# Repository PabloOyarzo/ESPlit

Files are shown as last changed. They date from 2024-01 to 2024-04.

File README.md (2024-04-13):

---
{}
---
# ESPlit

The ESPlit is an Ergonomic Split Keyboard based on the ESP32. Uses CHOC style switches, LiPo Battery and I2C connection through QWIC and TRRS connectors. 

[v0.2-alpha - KICAD Web view from KiCanvas](https://kicanvas.org/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)

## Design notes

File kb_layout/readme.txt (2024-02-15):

steps
1- design layout at http://www.keyboard-layout-editor.com/
2- download as json
3- run on the pcb editor the Keyboard Placer
	*see kbplacer_settings.jpg*
4- use "Shift + S" to switch Switches footprint
5- run the Keyboard Placer but without a json filed loaded

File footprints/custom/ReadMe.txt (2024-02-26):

Customs
x	TRRS
	Source: Keebio
	Changes:
		-expanded the silkscreen so doesn't collide with holes

x	SK6812-MINI-E
	NEO3535 	Eagle file  -> KiCAD 
	Source: https://github.com/adafruit/Adafruit-MacroPad-RP2040-PCB
	Changes:
		-added edge cut at rule area F.Cu
		-changed led icon to F.Fab
		-changed name to SK6812-E

x	D_0805
	Same name
	Source: https://github.com/keebio/Keebio-Parts.pretty
	Changes:
		-deleted overall rectangles around F.Silkscreen
		-and also deleted little pins from center icon
		-changed layers on names and ref

x	SW_Hotswap_Kailh_Choc_V1V2_Plated_1.00u
	Same name
	Source: Package Content Manager (PCM)
		Keyswitch Kicad Library
		https://github.com/perigoso/keyswitch-kicad-library
	Changes:
		-rotated on 180 degrees for convinience used on PCM_Keyboard_footprints_placer
		-also added 3d files wrl and stp.
		-deleted bottom mask

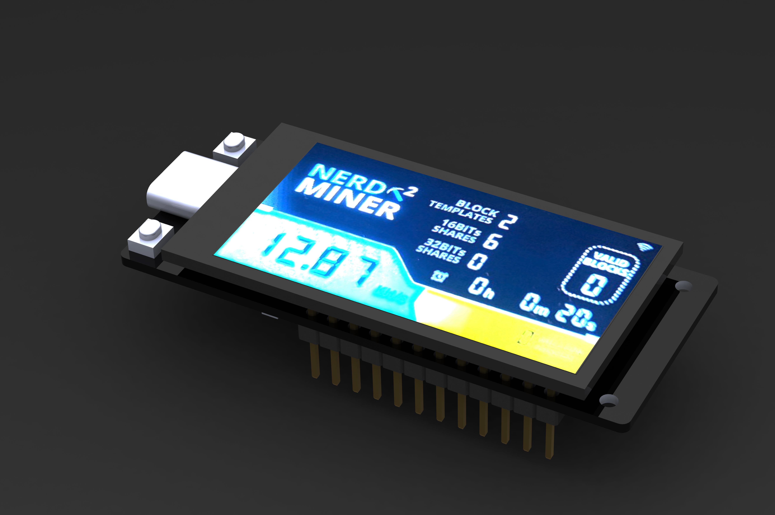
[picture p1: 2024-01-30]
footprints/T-Display-S3/board.jpg

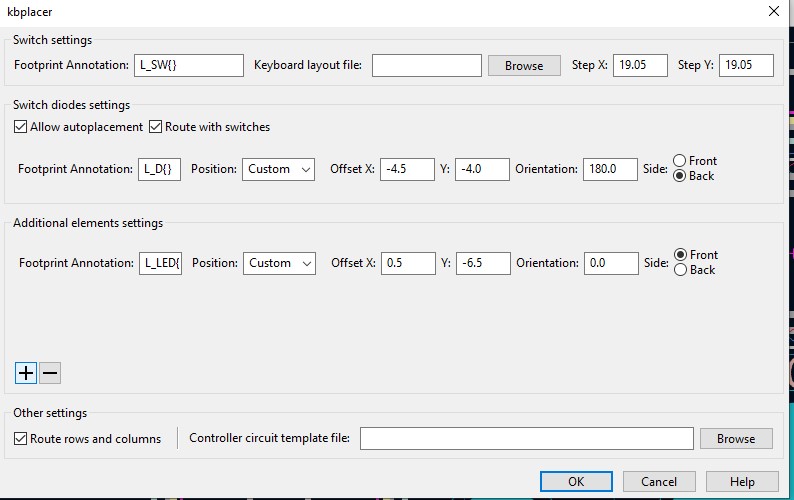
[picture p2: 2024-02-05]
kb_layout/kbplacer_settings.jpg

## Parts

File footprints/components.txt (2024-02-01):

MCU
x	T-Display-S3			https://github.com/ccadic/T-Display-S3-Kicad

MX Keys
x	MX key with Socket		https://github.com/daprice/keyswitches.pretty/tree/master
x	PRT12639 - TRRS			https://www.arrow.com/en/products/prt-12639/sparkfun-electronics

Else
x	TCA8418RTWR - IO Expander	https://www.arrow.com/en/products/tca8418rtwr/texas-instruments
x	SK6812-MINI-E RGB North facing	https://github.com/keebio/Keebio-Parts.pretty
x	0805 - Diode			https://github.com/keebio/Keebio-Parts.pretty
x	0805 - Caps			KiCAD 7
x	PCM13SMTR - Slide Switch	https://www.arrow.com/en/products/pcm13smtr/ck

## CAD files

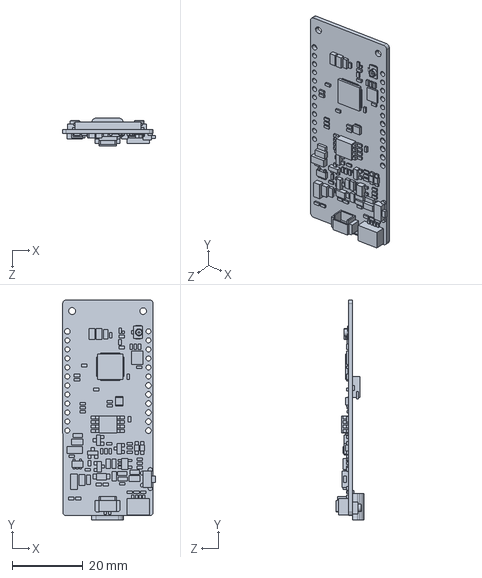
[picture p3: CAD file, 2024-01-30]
footprints/T-Display-S3/MainBoard_3D.SLDPRT
26.1 x 62.0 x 7.86 mm

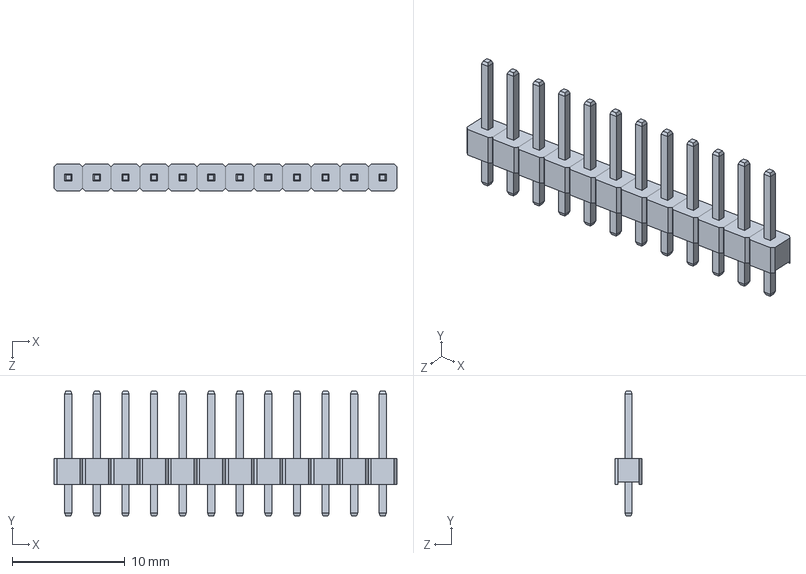
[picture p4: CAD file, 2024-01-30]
footprints/T-Display-S3/T-Display-Headers.SLDASM
30.5 x 11.1 x 2.40 mm
1_Male_Pin_2.54_mm x 12

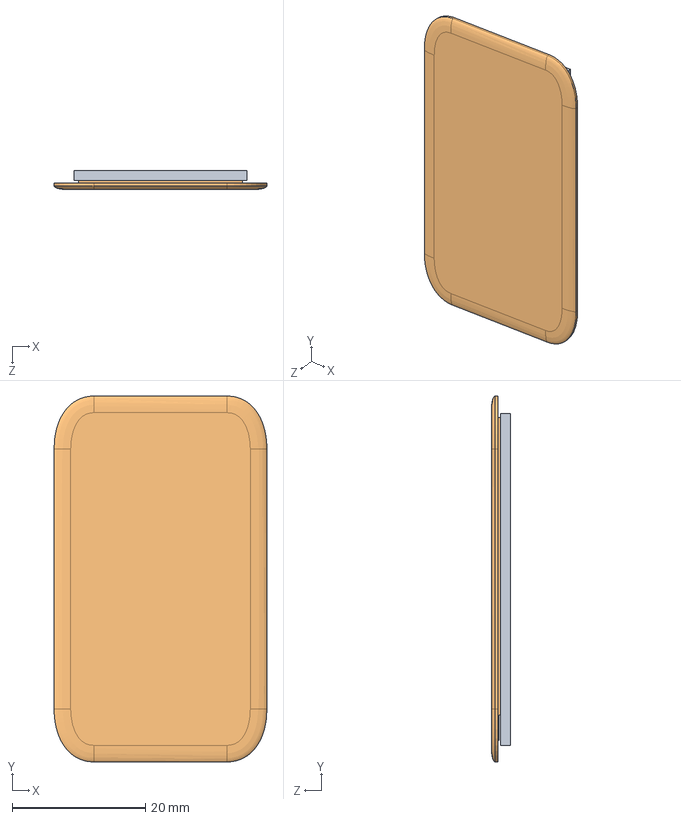
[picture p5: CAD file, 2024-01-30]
footprints/T-Display-S3/LCD_3D.SLDASM
32.0 x 55.0 x 2.93 mm

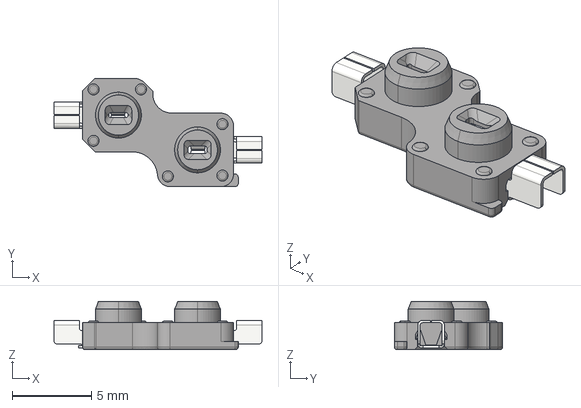
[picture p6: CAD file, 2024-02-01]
footprints/custom/SW_Hotswap_Kailh_Choc_V1.stp
13.2 x 6.85 x 3.05 mm

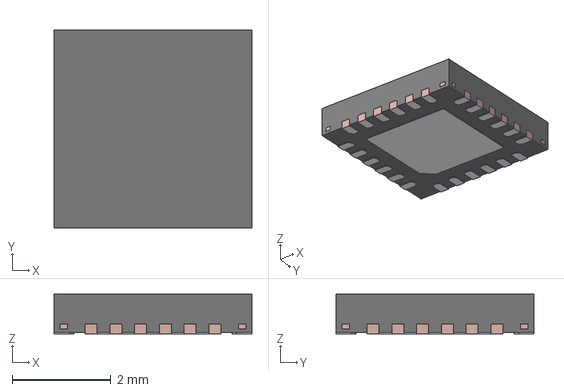
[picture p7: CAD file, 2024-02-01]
footprints/IO Expander - TCA8418RTWR/TCA8418RTWR.stp
4.00 x 4.00 x 0.8 mm
FRAME

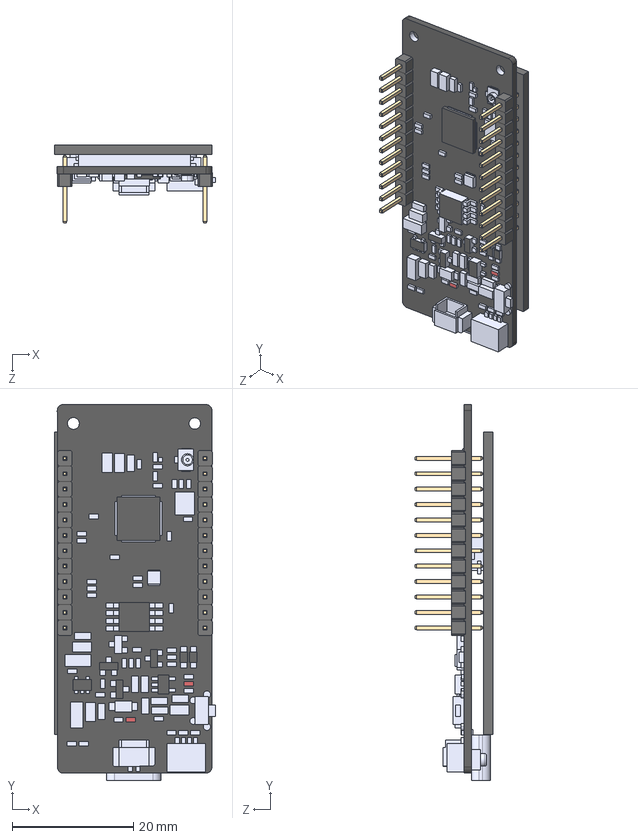
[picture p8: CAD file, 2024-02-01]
footprints/T-Display-S3/T-Display-S3.STEP
26.5 x 62.0 x 12.9 mm
MainBoard_3D
Ecran
1_Male_Pin_2.54_mm x 24

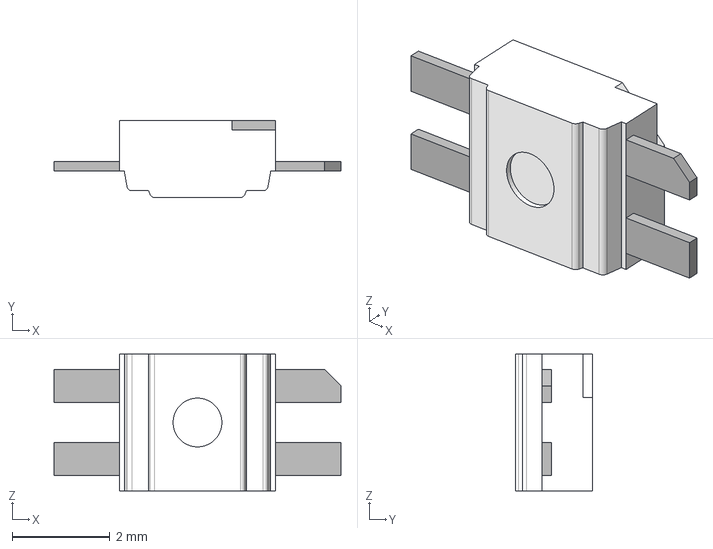
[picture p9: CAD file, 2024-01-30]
footprints/custom/SK6812-MINI-E.step
5.88 x 1.58 x 2.80 mm

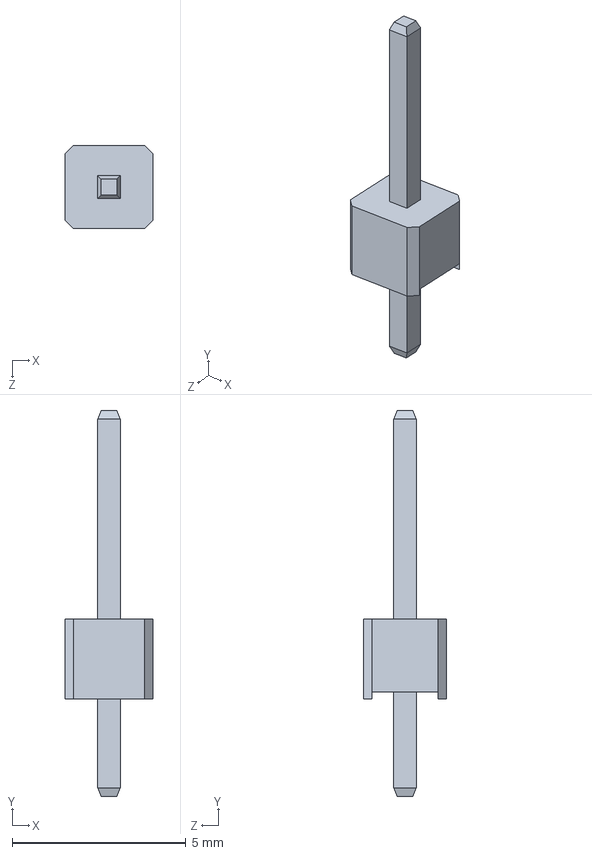
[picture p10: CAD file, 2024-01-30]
footprints/T-Display-S3/1_Male_Pin_2.54_mm.SLDPRT
2.54 x 11.1 x 2.40 mm

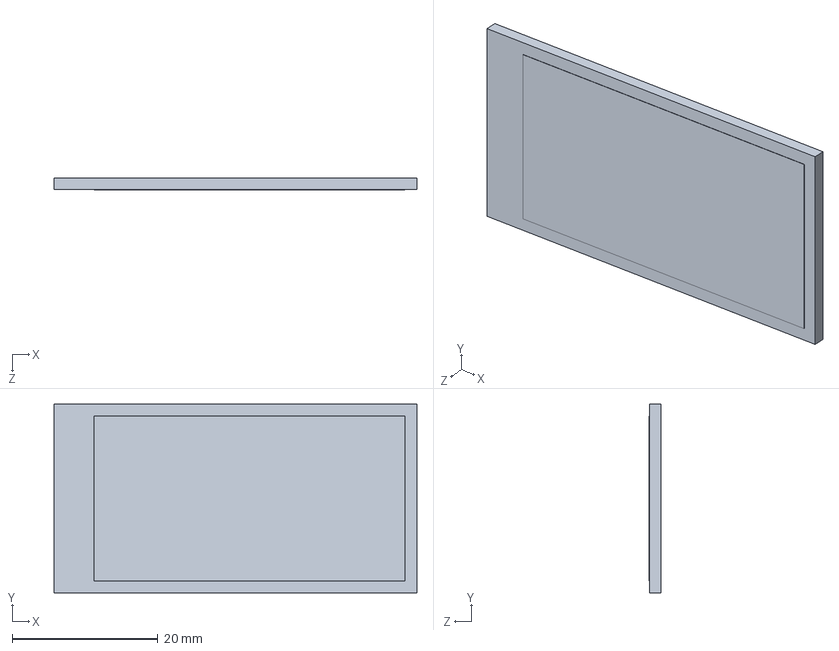
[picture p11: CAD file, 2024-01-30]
footprints/T-Display-S3/Ecran.SLDPRT
49.9 x 25.9 x 1.58 mm

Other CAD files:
footprints/T-Display-S3/T-Display-S3.SLDASM

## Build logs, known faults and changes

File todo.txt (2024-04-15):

Improvements TODO from the prototype manufactured from v0.2-alpha.

REQUIRED:
[x]	Fix Footprint:custom/SW_Hotswap_Kailh_Choc_V1V2_Plated_1.00u.kicad_mod
		> Add soldermask
[]	Change Design Rules
		> From PCBWay to => JLCPCB
[]	Add mount hole 6 to base plate
[]	Delete labels to mount holes
[]	Add pin header battery for outer port
[]	Add +/- label to Battery ports (front and back)
[]	Add label with each pin function for IO ports on top
[]	Jumper Pin 43/44
		> Add Labels
		> Make footprint bigger	
		> Further from pins 
		> Clean cut path
[]	Make hole for name on Top Plate
[]	Add Label on/off for switch
[]	Bigger font label for LED TPs
[]	Add ESD Protection to I2Cs

BETTER TO HAVE:
[]	Even rounder edge cuts
[]	Add PabloOyarzo/poka-yoke_rxtx
[]	Turn upside down pin labels for T-Display-S3

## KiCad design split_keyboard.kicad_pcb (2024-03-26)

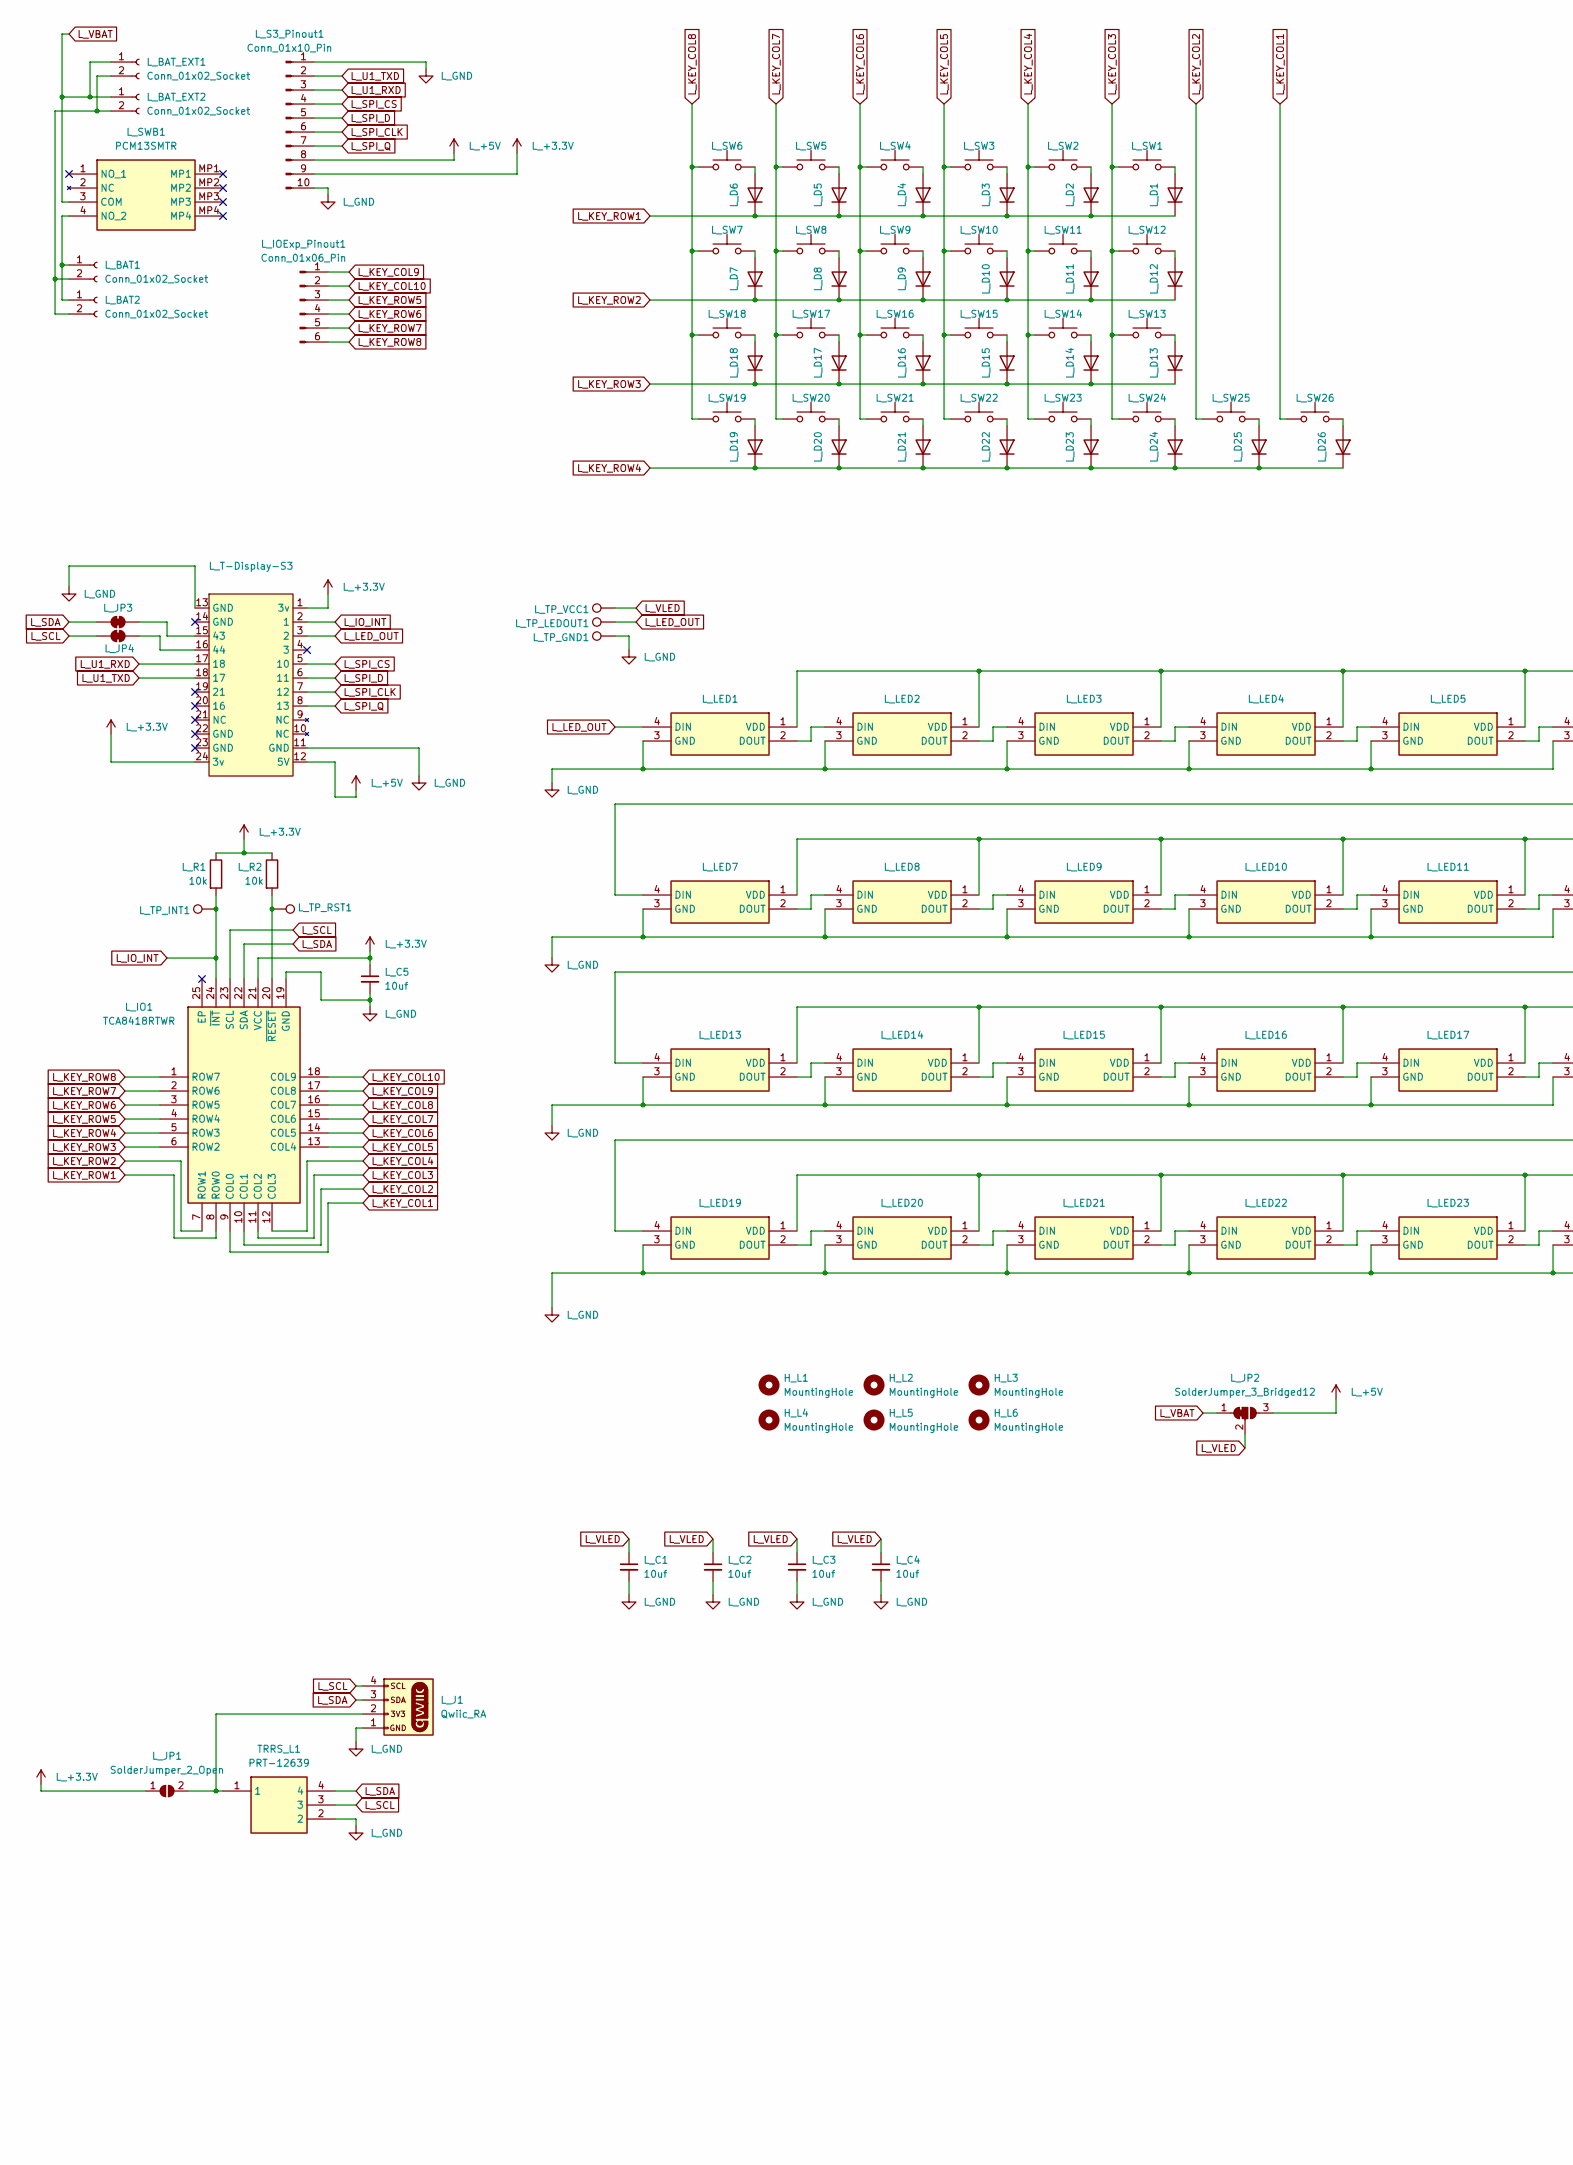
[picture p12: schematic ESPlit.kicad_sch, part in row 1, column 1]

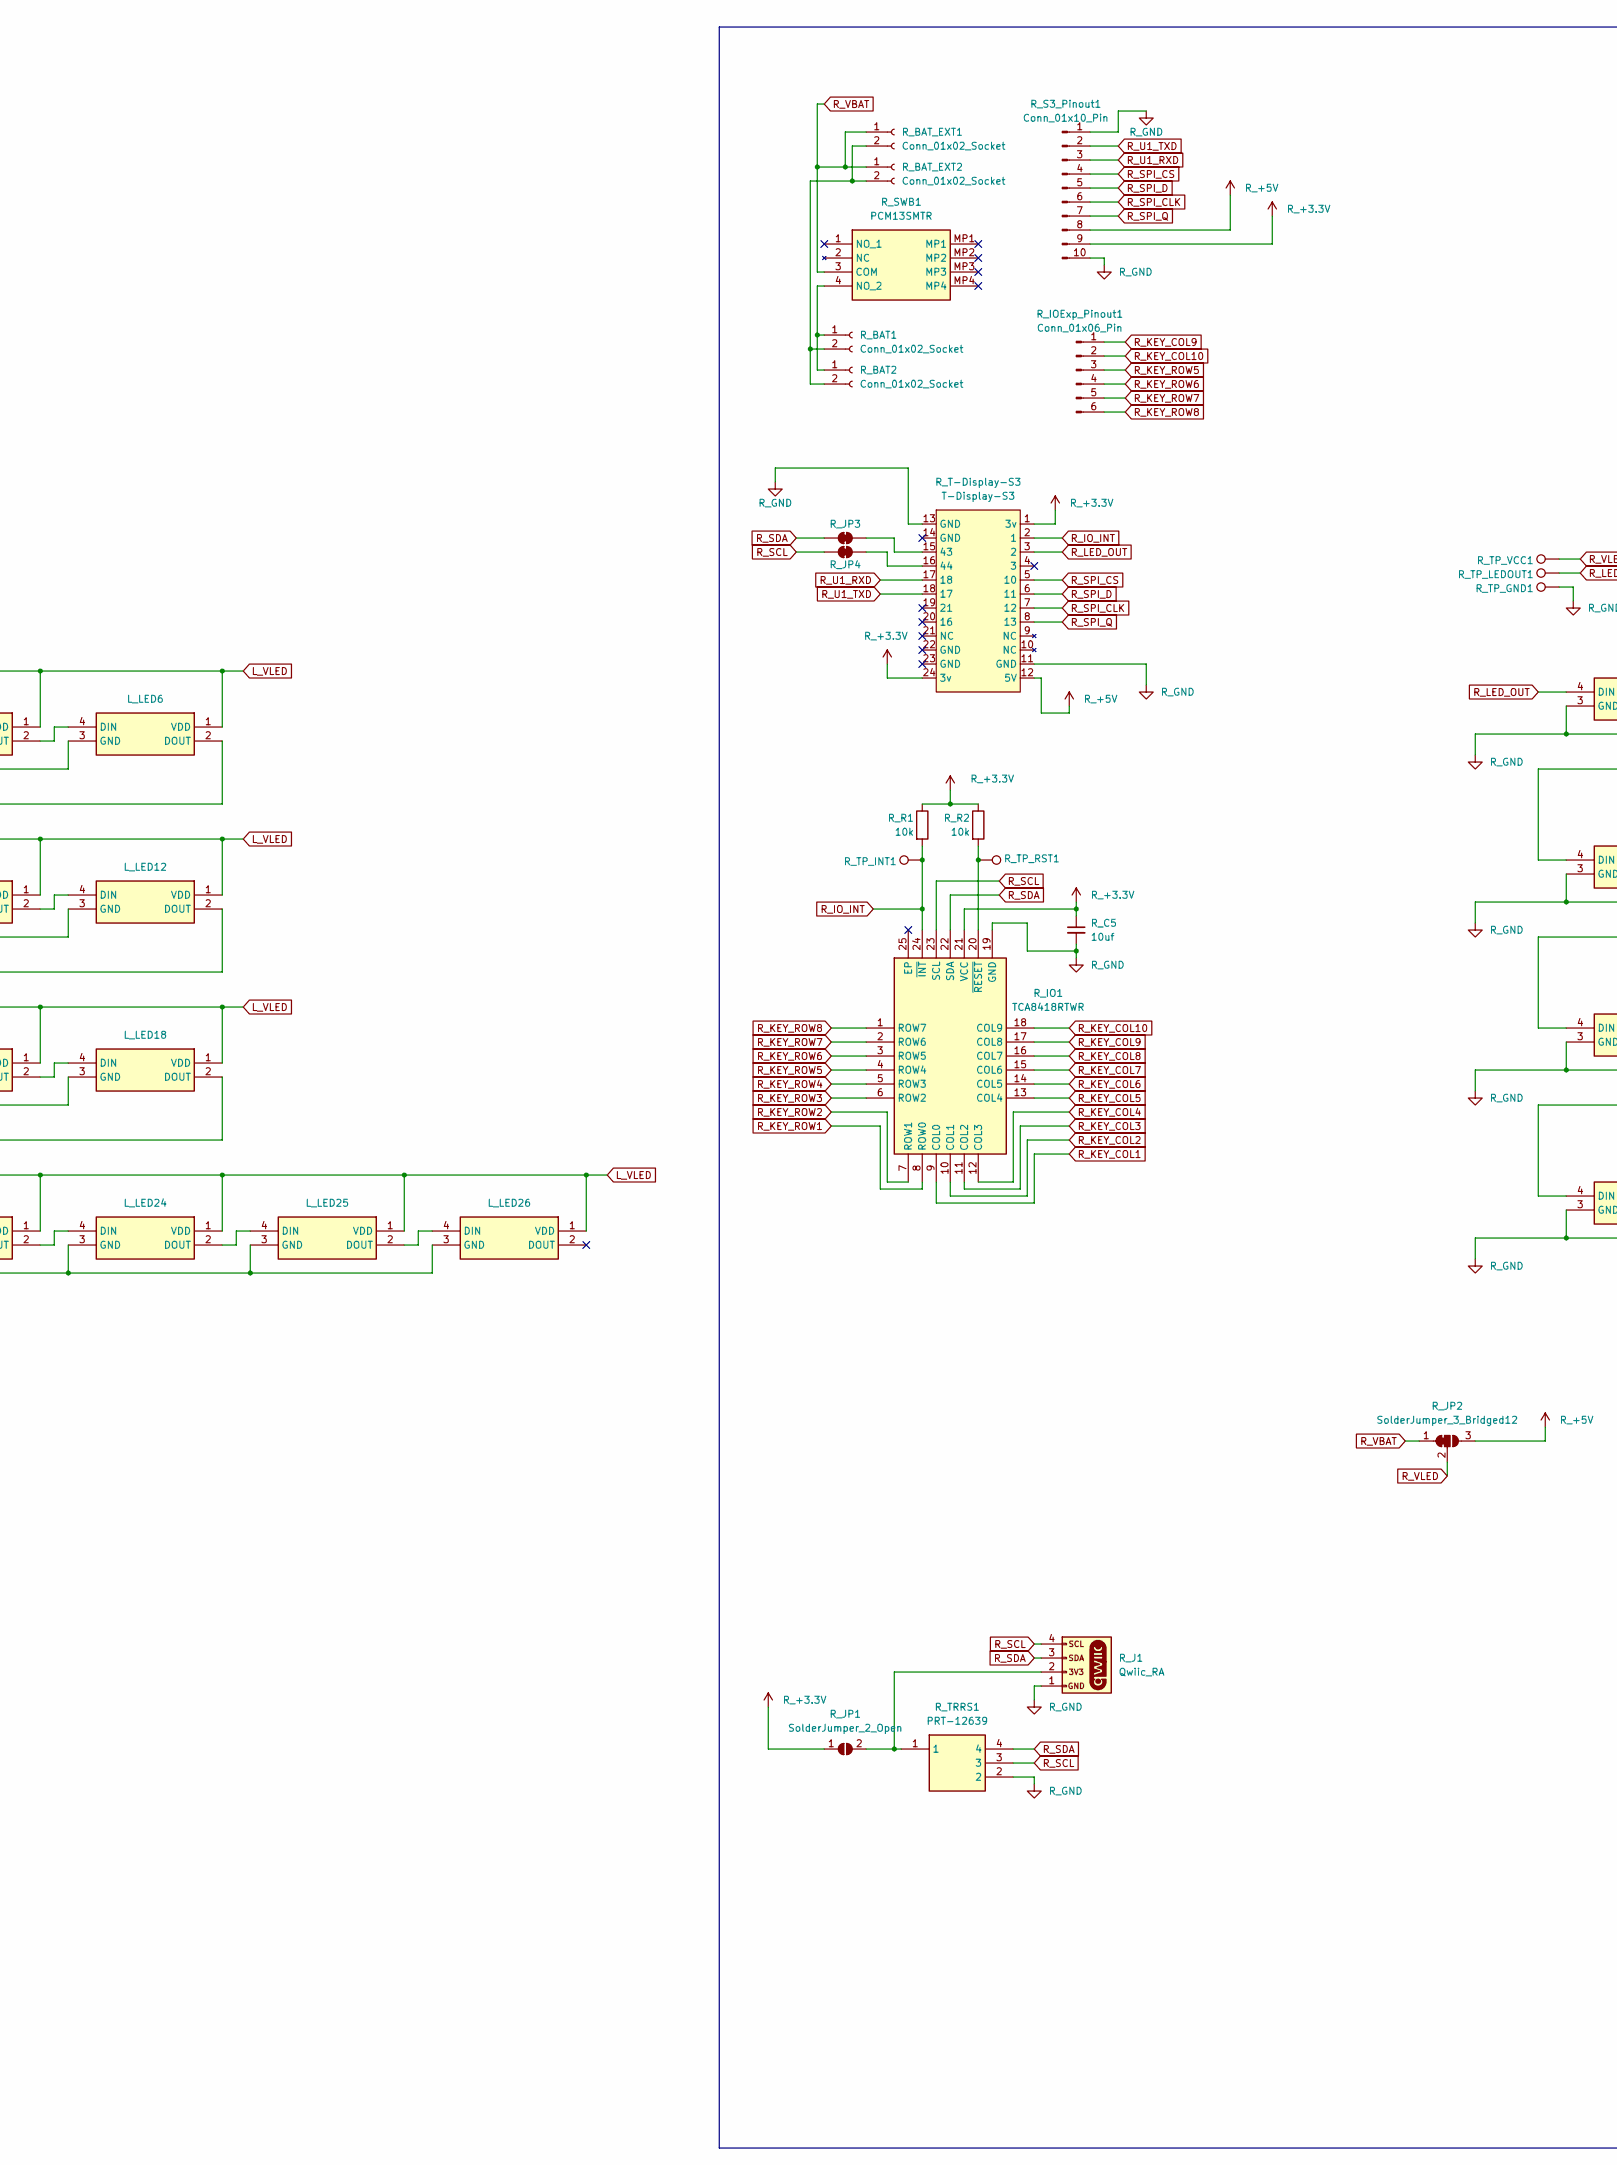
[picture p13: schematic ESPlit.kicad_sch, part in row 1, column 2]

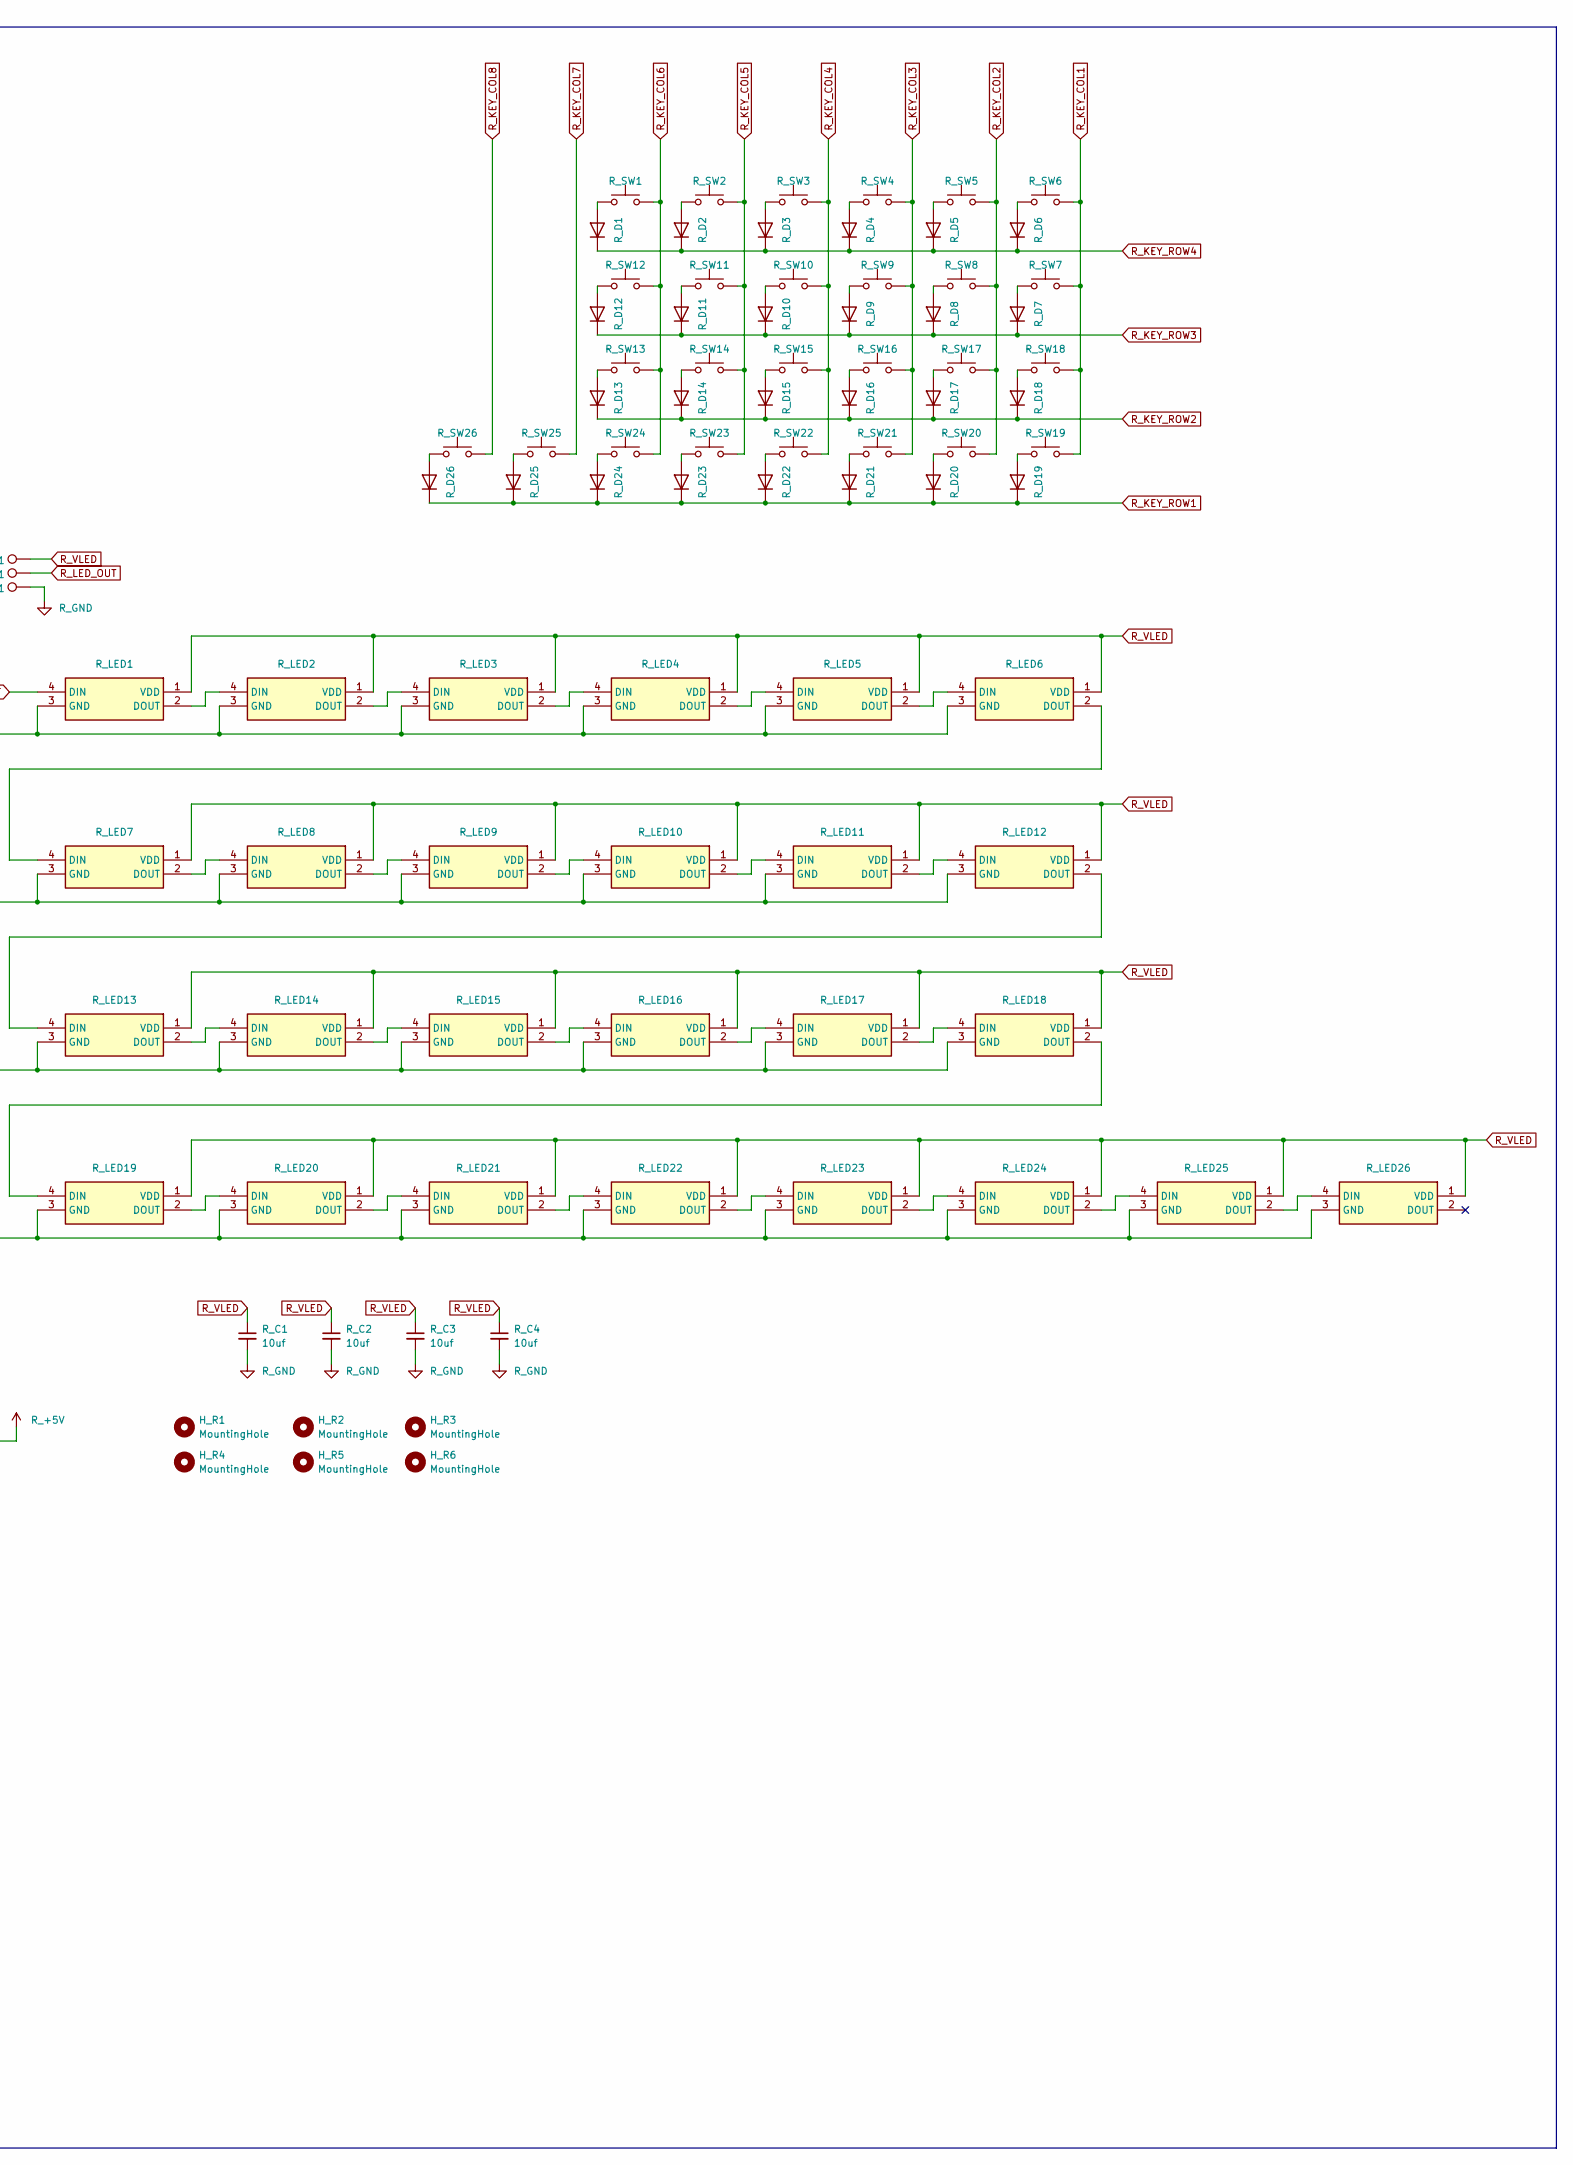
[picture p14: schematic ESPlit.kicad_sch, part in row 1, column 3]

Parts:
H_L1, H_L2, H_L3, H_L4, H_L5, H_L6: MountingHole; MountingHole_2.5mm_Pad_TopBottom
H_R1, H_R2, H_R3, H_R4, H_R5, H_R6: MountingHole; MountingHole_2.5mm_Pad_TopBottom
L_BAT1: Conn_01x02_Socket; JST_PH_B2B-PH-SM4-TB_02x2.00mm_Straight
L_BAT2: Conn_01x02_Socket; JST_GH_BM02B-GHS-TBT_02x1.25mm_Straight
L_BAT_EXT1: Conn_01x02_Socket; JST_PH_B2B-PH-SM4-TB_02x2.00mm_Straight
L_BAT_EXT2: Conn_01x02_Socket; PinHeader_1x02_P2.54mm_Vertical
L_C1, L_C2, L_C3, L_C4, L_C5: 10uf; C_0805_2012Metric
L_D1, L_D2, L_D3, L_D4, L_D5, L_D6, L_D7, L_D8, L_D9, L_D10, L_D11, L_D12, L_D13, L_D14, L_D15, L_D16, L_D17, L_D18, L_D19, L_D20, L_D21, L_D22, L_D23, L_D24, L_D25, L_D26: D; D_0805
L_IO1: TCA8418RTWR; QFN50P400X400X80-25N; Manufacturer_Part_Number TCA8418RTWR
L_IOExp_Pinout1: Conn_01x06_Pin; PinHeader_1x06_P2.54mm_Vertical
L_J1: Qwiic_RA; JST_SMD_1.0mm-4_RA
L_JP1: SolderJumper_2_Open; SolderJumper-2_P1.3mm_Open_TrianglePad1.0x1.5mm
L_JP2: SolderJumper_3_Bridged12; SolderJumper-3_P1.3mm_Bridged12_RoundedPad1.0x1.5mm
L_JP3, L_JP4: Measure; Jumper_2_NC_Trace_NoSilk
L_LED1, L_LED2, L_LED3, L_LED4, L_LED5, L_LED6, L_LED7, L_LED8, L_LED9, L_LED10, L_LED11, L_LED12, L_LED13, L_LED14, L_LED15, L_LED16, L_LED17, L_LED18, L_LED19, L_LED20, L_LED21, L_LED22, L_LED23, L_LED24, L_LED25, L_LED26: SK6812MINI-E; SK6812-MINI-E; Manufacturer_Part_Number SK6812MINI-E
L_R1, L_R2: 10k; R_0805_2012Metric
L_S3_Pinout1: Conn_01x10_Pin; PinHeader_1x10_P2.54mm_Vertical
L_SW1, L_SW2, L_SW3, L_SW4, L_SW5, L_SW6, L_SW7, L_SW8, L_SW9, L_SW10, L_SW11, L_SW12, L_SW13, L_SW14, L_SW15, L_SW16, L_SW17, L_SW18, L_SW19, L_SW20, L_SW21, L_SW22, L_SW23, L_SW24, L_SW25, L_SW26: L_SW; SW_Hotswap_Kailh_Choc_V1V2_Plated_1.00u
L_SWB1: PCM13SMTR; Manufacturer_Part_Number PCM13SMTR
L_T-Display-S3: T-Display-S3
L_TP_GND1: 1.25mm; TestPoint-1.25mm
L_TP_INT1: 1.25mm; TestPoint-1.25mm
L_TP_LEDOUT1: 1.25mm; TestPoint-1.25mm
L_TP_RST1: 1.25mm; TestPoint-1.25mm
L_TP_VCC1: 1.25mm; TestPoint-1.25mm
R_BAT1: Conn_01x02_Socket; JST_PH_B2B-PH-SM4-TB_02x2.00mm_Straight
R_BAT2: Conn_01x02_Socket; JST_GH_BM02B-GHS-TBT_02x1.25mm_Straight
R_BAT_EXT1: Conn_01x02_Socket; JST_PH_B2B-PH-SM4-TB_02x2.00mm_Straight
R_BAT_EXT2: Conn_01x02_Socket; PinHeader_1x02_P2.54mm_Vertical
R_C1, R_C2, R_C3, R_C4, R_C5: 10uf; C_0805_2012Metric
R_D1, R_D2, R_D3, R_D4, R_D5, R_D6, R_D7, R_D8, R_D9, R_D10, R_D11, R_D12, R_D13, R_D14, R_D15, R_D16, R_D17, R_D18, R_D19, R_D20, R_D21, R_D22, R_D23, R_D24, R_D25, R_D26: D; D_0805
R_IO1: TCA8418RTWR; QFN50P400X400X80-25N; Manufacturer_Part_Number TCA8418RTWR
R_IOExp_Pinout1: Conn_01x06_Pin; PinHeader_1x06_P2.54mm_Vertical
R_J1: Qwiic_RA; JST_SMD_1.0mm-4_RA
R_JP1: SolderJumper_2_Open; SolderJumper-2_P1.3mm_Open_TrianglePad1.0x1.5mm
R_JP2: SolderJumper_3_Bridged12; SolderJumper-3_P1.3mm_Bridged12_RoundedPad1.0x1.5mm
R_JP3, R_JP4: Measure; Jumper_2_NC_Trace_NoSilk
R_LED1, R_LED2, R_LED3, R_LED4, R_LED5, R_LED6, R_LED7, R_LED8, R_LED9, R_LED10, R_LED11, R_LED12, R_LED13, R_LED14, R_LED15, R_LED16, R_LED17, R_LED18, R_LED19, R_LED20, R_LED21, R_LED22, R_LED23, R_LED24, R_LED25, R_LED26: SK6812MINI-E; SK6812-MINI-E; Manufacturer_Part_Number SK6812MINI-E
R_R1, R_R2: 10k; R_0805_2012Metric
R_S3_Pinout1: Conn_01x10_Pin; PinHeader_1x10_P2.54mm_Vertical
R_SW1, R_SW2, R_SW3, R_SW4, R_SW5, R_SW6, R_SW7, R_SW8, R_SW9, R_SW10, R_SW11, R_SW12, R_SW13, R_SW14, R_SW15, R_SW16, R_SW17, R_SW18, R_SW19, R_SW20, R_SW21, R_SW22, R_SW23, R_SW24, R_SW25, R_SW26: L_SW; SW_Hotswap_Kailh_Choc_V1V2_Plated_1.00u
R_SWB1: PCM13SMTR; Manufacturer_Part_Number PCM13SMTR
R_T-Display-S3: T-Display-S3
R_TP_GND1: 1.25mm; TestPoint-1.25mm
R_TP_INT1: 1.25mm; TestPoint-1.25mm
R_TP_LEDOUT1: 1.25mm; TestPoint-1.25mm
R_TP_RST1: 1.25mm; TestPoint-1.25mm
R_TP_VCC1: 1.25mm; TestPoint-1.25mm
R_TRRS1: PRT-12639; TRRS-PJ-320A; Manufacturer_Part_Number PRT-12639
TRRS_L1: PRT-12639; TRRS-PJ-320A; Manufacturer_Part_Number PRT-12639

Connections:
L_+3.3V: L_C5.1, L_IO1.21 (VCC), L_JP1.1 (A), L_R1.1, L_R2.1, L_S3_Pinout1.9, L_T-Display-S3.1 (3v), L_T-Display-S3.24 (3v)
L_+5V: L_JP2.3 (B), L_S3_Pinout1.8, L_T-Display-S3.12 (5V)
L_GND: L_C1.2, L_C2.2, L_C3.2, L_C4.2, L_C5.2, L_IO1.19 (GND), L_J1.1, L_LED1.3 (GND), L_LED2.3 (GND), L_LED3.3 (GND), L_LED4.3 (GND), L_LED5.3 (GND), L_LED6.3 (GND), L_LED7.3 (GND), L_LED8.3 (GND), L_LED9.3 (GND), L_LED10.3 (GND), L_LED11.3 (GND), L_LED12.3 (GND), L_LED13.3 (GND), L_LED14.3 (GND), L_LED15.3 (GND), L_LED16.3 (GND), L_LED17.3 (GND), L_LED18.3 (GND), L_LED19.3 (GND), L_LED20.3 (GND), L_LED21.3 (GND), L_LED22.3 (GND), L_LED23.3 (GND), L_LED24.3 (GND), L_LED25.3 (GND), L_LED26.3 (GND), L_S3_Pinout1.1, L_S3_Pinout1.10, L_T-Display-S3.11 (GND), L_T-Display-S3.13 (GND), L_TP_GND1.1, TRRS_L1.2
L_IO_INT: L_IO1.24 (~INT), L_R1.2, L_T-Display-S3.2 (1), L_TP_INT1.1
L_KEY_COL1: L_IO1.9 (COL0), L_SW26.1
L_KEY_COL2: L_IO1.10 (COL1), L_SW25.1
L_KEY_COL3: L_IO1.11 (COL2), L_SW1.1, L_SW12.1, L_SW13.1, L_SW24.1
L_KEY_COL4: L_IO1.12 (COL3), L_SW2.1, L_SW11.1, L_SW14.1, L_SW23.1
L_KEY_COL5: L_IO1.13 (COL4), L_SW3.1, L_SW10.1, L_SW15.1, L_SW22.1
L_KEY_COL6: L_IO1.14 (COL5), L_SW4.1, L_SW9.1, L_SW16.1, L_SW21.1
L_KEY_COL7: L_IO1.15 (COL6), L_SW5.1, L_SW8.1, L_SW17.1, L_SW20.1
L_KEY_COL8: L_IO1.16 (COL7), L_SW6.1, L_SW7.1, L_SW18.1, L_SW19.1
L_KEY_COL9: L_IO1.17 (COL8), L_IOExp_Pinout1.1
L_KEY_COL10: L_IO1.18 (COL9), L_IOExp_Pinout1.2
L_KEY_ROW1: L_D1.1 (K), L_D2.1 (K), L_D3.1 (K), L_D4.1 (K), L_D5.1 (K), L_D6.1 (K), L_IO1.8 (ROW0)
L_KEY_ROW2: L_D7.1 (K), L_D8.1 (K), L_D9.1 (K), L_D10.1 (K), L_D11.1 (K), L_D12.1 (K), L_IO1.7 (ROW1)
L_KEY_ROW3: L_D13.1 (K), L_D14.1 (K), L_D15.1 (K), L_D16.1 (K), L_D17.1 (K), L_D18.1 (K), L_IO1.6 (ROW2)
L_KEY_ROW4: L_D19.1 (K), L_D20.1 (K), L_D21.1 (K), L_D22.1 (K), L_D23.1 (K), L_D24.1 (K), L_D25.1 (K), L_D26.1 (K), L_IO1.5 (ROW3)
L_KEY_ROW5: L_IO1.4 (ROW4), L_IOExp_Pinout1.3
L_KEY_ROW6: L_IO1.3 (ROW5), L_IOExp_Pinout1.4
L_KEY_ROW7: L_IO1.2 (ROW6), L_IOExp_Pinout1.5
L_KEY_ROW8: L_IO1.1 (ROW7), L_IOExp_Pinout1.6
L_LED_OUT: L_LED1.4 (DIN), L_T-Display-S3.3 (2), L_TP_LEDOUT1.1
L_SCL: L_IO1.23 (SCL), L_J1.4, L_JP4.1 (A), TRRS_L1.3
L_SDA: L_IO1.22 (SDA), L_J1.3, L_JP3.1 (A), TRRS_L1.4
L_SPI_CLK: L_S3_Pinout1.6, L_T-Display-S3.7 (12)
L_SPI_CS: L_S3_Pinout1.4, L_T-Display-S3.5 (10)
L_SPI_D: L_S3_Pinout1.5, L_T-Display-S3.6 (11)
L_SPI_Q: L_S3_Pinout1.7, L_T-Display-S3.8 (13)
L_U1_RXD: L_S3_Pinout1.3, L_T-Display-S3.17 (18)
L_U1_TXD: L_S3_Pinout1.2, L_T-Display-S3.18 (17)
L_VBAT: L_BAT_EXT1.1, L_BAT_EXT2.1, L_JP2.1 (A), L_SWB1.3 (COM)
L_VLED: L_C1.1, L_C2.1, L_C3.1, L_C4.1, L_JP2.2 (C), L_LED1.1 (VDD), L_LED2.1 (VDD), L_LED3.1 (VDD), L_LED4.1 (VDD), L_LED5.1 (VDD), L_LED6.1 (VDD), L_LED7.1 (VDD), L_LED8.1 (VDD), L_LED9.1 (VDD), L_LED10.1 (VDD), L_LED11.1 (VDD), L_LED12.1 (VDD), L_LED13.1 (VDD), L_LED14.1 (VDD), L_LED15.1 (VDD), L_LED16.1 (VDD), L_LED17.1 (VDD), L_LED18.1 (VDD), L_LED19.1 (VDD), L_LED20.1 (VDD), L_LED21.1 (VDD), L_LED22.1 (VDD), L_LED23.1 (VDD), L_LED24.1 (VDD), L_LED25.1 (VDD), L_LED26.1 (VDD), L_TP_VCC1.1
unnamed: L_BAT1.1, L_BAT2.1, L_SWB1.4 (NO_2)
unnamed: L_BAT1.2, L_BAT2.2, L_BAT_EXT1.2, L_BAT_EXT2.2
unnamed: L_D1.2 (A), L_SW1.2
unnamed: L_D2.2 (A), L_SW2.2
unnamed: L_D3.2 (A), L_SW3.2
unnamed: L_D4.2 (A), L_SW4.2
unnamed: L_D5.2 (A), L_SW5.2
unnamed: L_D6.2 (A), L_SW6.2
unnamed: L_D7.2 (A), L_SW7.2
unnamed: L_D8.2 (A), L_SW8.2
unnamed: L_D9.2 (A), L_SW9.2
unnamed: L_D10.2 (A), L_SW10.2
unnamed: L_D11.2 (A), L_SW11.2
unnamed: L_D12.2 (A), L_SW12.2
unnamed: L_D13.2 (A), L_SW13.2
unnamed: L_D14.2 (A), L_SW14.2
unnamed: L_D15.2 (A), L_SW15.2
unnamed: L_D16.2 (A), L_SW16.2
unnamed: L_D17.2 (A), L_SW17.2
unnamed: L_D18.2 (A), L_SW18.2
unnamed: L_D19.2 (A), L_SW19.2
unnamed: L_D20.2 (A), L_SW20.2
unnamed: L_D21.2 (A), L_SW21.2
unnamed: L_D22.2 (A), L_SW22.2
unnamed: L_D23.2 (A), L_SW23.2
unnamed: L_D24.2 (A), L_SW24.2
unnamed: L_D25.2 (A), L_SW25.2
unnamed: L_D26.2 (A), L_SW26.2
unnamed: L_IO1.20 (~RESET), L_R2.2, L_TP_RST1.1
unnamed: L_J1.2, L_JP1.2 (B), TRRS_L1.1
unnamed: L_JP3.2 (B), L_T-Display-S3.15 (43)
unnamed: L_JP4.2 (B), L_T-Display-S3.16 (44)
unnamed: L_LED1.2 (DOUT), L_LED2.4 (DIN)
unnamed: L_LED2.2 (DOUT), L_LED3.4 (DIN)
unnamed: L_LED3.2 (DOUT), L_LED4.4 (DIN)
unnamed: L_LED4.2 (DOUT), L_LED5.4 (DIN)
unnamed: L_LED5.2 (DOUT), L_LED6.4 (DIN)
unnamed: L_LED6.2 (DOUT), L_LED7.4 (DIN)
unnamed: L_LED7.2 (DOUT), L_LED8.4 (DIN)
unnamed: L_LED8.2 (DOUT), L_LED9.4 (DIN)
unnamed: L_LED9.2 (DOUT), L_LED10.4 (DIN)
unnamed: L_LED10.2 (DOUT), L_LED11.4 (DIN)
unnamed: L_LED11.2 (DOUT), L_LED12.4 (DIN)
unnamed: L_LED12.2 (DOUT), L_LED13.4 (DIN)
unnamed: L_LED13.2 (DOUT), L_LED14.4 (DIN)
unnamed: L_LED14.2 (DOUT), L_LED15.4 (DIN)
unnamed: L_LED15.2 (DOUT), L_LED16.4 (DIN)
unnamed: L_LED16.2 (DOUT), L_LED17.4 (DIN)
unnamed: L_LED17.2 (DOUT), L_LED18.4 (DIN)
unnamed: L_LED18.2 (DOUT), L_LED19.4 (DIN)
unnamed: L_LED19.2 (DOUT), L_LED20.4 (DIN)
unnamed: L_LED20.2 (DOUT), L_LED21.4 (DIN)
unnamed: L_LED21.2 (DOUT), L_LED22.4 (DIN)
unnamed: L_LED22.2 (DOUT), L_LED23.4 (DIN)
unnamed: L_LED23.2 (DOUT), L_LED24.4 (DIN)
unnamed: L_LED24.2 (DOUT), L_LED25.4 (DIN)
unnamed: L_LED25.2 (DOUT), L_LED26.4 (DIN)
unnamed: R_BAT1.1, R_BAT2.1, R_SWB1.4 (NO_2)
unnamed: R_BAT1.2, R_BAT2.2, R_BAT_EXT1.2, R_BAT_EXT2.2
unnamed: R_D1.2 (A), R_SW1.2
unnamed: R_D2.2 (A), R_SW2.2
unnamed: R_D3.2 (A), R_SW3.2
unnamed: R_D4.2 (A), R_SW4.2
unnamed: R_D5.2 (A), R_SW5.2
unnamed: R_D6.2 (A), R_SW6.2
unnamed: R_D7.2 (A), R_SW7.2
unnamed: R_D8.2 (A), R_SW8.2
unnamed: R_D9.2 (A), R_SW9.2
unnamed: R_D10.2 (A), R_SW10.2
unnamed: R_D11.2 (A), R_SW11.2
unnamed: R_D12.2 (A), R_SW12.2
unnamed: R_D13.2 (A), R_SW13.2
unnamed: R_D14.2 (A), R_SW14.2
unnamed: R_D15.2 (A), R_SW15.2
unnamed: R_D16.2 (A), R_SW16.2
unnamed: R_D17.2 (A), R_SW17.2
unnamed: R_D18.2 (A), R_SW18.2
unnamed: R_D19.2 (A), R_SW19.2
unnamed: R_D20.2 (A), R_SW20.2
unnamed: R_D21.2 (A), R_SW21.2
unnamed: R_D22.2 (A), R_SW22.2
unnamed: R_D23.2 (A), R_SW23.2
unnamed: R_D24.2 (A), R_SW24.2
unnamed: R_D25.2 (A), R_SW25.2
unnamed: R_D26.2 (A), R_SW26.2
unnamed: R_IO1.20 (~RESET), R_R2.2, R_TP_RST1.1
unnamed: R_J1.2, R_JP1.2 (B), R_TRRS1.1
unnamed: R_JP3.2 (B), R_T-Display-S3.15 (43)
unnamed: R_JP4.2 (B), R_T-Display-S3.16 (44)
unnamed: R_LED1.2 (DOUT), R_LED2.4 (DIN)
unnamed: R_LED2.2 (DOUT), R_LED3.4 (DIN)
unnamed: R_LED3.2 (DOUT), R_LED4.4 (DIN)
unnamed: R_LED4.2 (DOUT), R_LED5.4 (DIN)
unnamed: R_LED5.2 (DOUT), R_LED6.4 (DIN)
unnamed: R_LED6.2 (DOUT), R_LED7.4 (DIN)
unnamed: R_LED7.2 (DOUT), R_LED8.4 (DIN)
unnamed: R_LED8.2 (DOUT), R_LED9.4 (DIN)
unnamed: R_LED9.2 (DOUT), R_LED10.4 (DIN)
unnamed: R_LED10.2 (DOUT), R_LED11.4 (DIN)
unnamed: R_LED11.2 (DOUT), R_LED12.4 (DIN)
unnamed: R_LED12.2 (DOUT), R_LED13.4 (DIN)
unnamed: R_LED13.2 (DOUT), R_LED14.4 (DIN)
unnamed: R_LED14.2 (DOUT), R_LED15.4 (DIN)
unnamed: R_LED15.2 (DOUT), R_LED16.4 (DIN)
unnamed: R_LED16.2 (DOUT), R_LED17.4 (DIN)
unnamed: R_LED17.2 (DOUT), R_LED18.4 (DIN)
unnamed: R_LED18.2 (DOUT), R_LED19.4 (DIN)
unnamed: R_LED19.2 (DOUT), R_LED20.4 (DIN)
unnamed: R_LED20.2 (DOUT), R_LED21.4 (DIN)
unnamed: R_LED21.2 (DOUT), R_LED22.4 (DIN)
unnamed: R_LED22.2 (DOUT), R_LED23.4 (DIN)
unnamed: R_LED23.2 (DOUT), R_LED24.4 (DIN)
unnamed: R_LED24.2 (DOUT), R_LED25.4 (DIN)
unnamed: R_LED25.2 (DOUT), R_LED26.4 (DIN)
R_+3.3V: R_C5.1, R_IO1.21 (VCC), R_JP1.1 (A), R_R1.1, R_R2.1, R_S3_Pinout1.9, R_T-Display-S3.1 (3v), R_T-Display-S3.24 (3v)
R_+5V: R_JP2.3 (B), R_S3_Pinout1.8, R_T-Display-S3.12 (5V)
R_GND: R_C1.2, R_C2.2, R_C3.2, R_C4.2, R_C5.2, R_IO1.19 (GND), R_J1.1, R_LED1.3 (GND), R_LED2.3 (GND), R_LED3.3 (GND), R_LED4.3 (GND), R_LED5.3 (GND), R_LED6.3 (GND), R_LED7.3 (GND), R_LED8.3 (GND), R_LED9.3 (GND), R_LED10.3 (GND), R_LED11.3 (GND), R_LED12.3 (GND), R_LED13.3 (GND), R_LED14.3 (GND), R_LED15.3 (GND), R_LED16.3 (GND), R_LED17.3 (GND), R_LED18.3 (GND), R_LED19.3 (GND), R_LED20.3 (GND), R_LED21.3 (GND), R_LED22.3 (GND), R_LED23.3 (GND), R_LED24.3 (GND), R_LED25.3 (GND), R_LED26.3 (GND), R_S3_Pinout1.1, R_S3_Pinout1.10, R_T-Display-S3.11 (GND), R_T-Display-S3.13 (GND), R_TP_GND1.1, R_TRRS1.2
R_IO_INT: R_IO1.24 (~INT), R_R1.2, R_T-Display-S3.2 (1), R_TP_INT1.1
R_KEY_COL1: R_IO1.9 (COL0), R_SW6.1, R_SW7.1, R_SW18.1, R_SW19.1
R_KEY_COL2: R_IO1.10 (COL1), R_SW5.1, R_SW8.1, R_SW17.1, R_SW20.1
R_KEY_COL3: R_IO1.11 (COL2), R_SW4.1, R_SW9.1, R_SW16.1, R_SW21.1
R_KEY_COL4: R_IO1.12 (COL3), R_SW3.1, R_SW10.1, R_SW15.1, R_SW22.1
R_KEY_COL5: R_IO1.13 (COL4), R_SW2.1, R_SW11.1, R_SW14.1, R_SW23.1
R_KEY_COL6: R_IO1.14 (COL5), R_SW1.1, R_SW12.1, R_SW13.1, R_SW24.1
R_KEY_COL7: R_IO1.15 (COL6), R_SW25.1
R_KEY_COL8: R_IO1.16 (COL7), R_SW26.1
R_KEY_COL9: R_IO1.17 (COL8), R_IOExp_Pinout1.1
R_KEY_COL10: R_IO1.18 (COL9), R_IOExp_Pinout1.2
R_KEY_ROW1: R_D19.1 (K), R_D20.1 (K), R_D21.1 (K), R_D22.1 (K), R_D23.1 (K), R_D24.1 (K), R_D25.1 (K), R_D26.1 (K), R_IO1.8 (ROW0)
R_KEY_ROW2: R_D13.1 (K), R_D14.1 (K), R_D15.1 (K), R_D16.1 (K), R_D17.1 (K), R_D18.1 (K), R_IO1.7 (ROW1)
R_KEY_ROW3: R_D7.1 (K), R_D8.1 (K), R_D9.1 (K), R_D10.1 (K), R_D11.1 (K), R_D12.1 (K), R_IO1.6 (ROW2)
R_KEY_ROW4: R_D1.1 (K), R_D2.1 (K), R_D3.1 (K), R_D4.1 (K), R_D5.1 (K), R_D6.1 (K), R_IO1.5 (ROW3)
R_KEY_ROW5: R_IO1.4 (ROW4), R_IOExp_Pinout1.3
R_KEY_ROW6: R_IO1.3 (ROW5), R_IOExp_Pinout1.4
R_KEY_ROW7: R_IO1.2 (ROW6), R_IOExp_Pinout1.5
R_KEY_ROW8: R_IO1.1 (ROW7), R_IOExp_Pinout1.6
R_LED_OUT: R_LED1.4 (DIN), R_T-Display-S3.3 (2), R_TP_LEDOUT1.1
R_SCL: R_IO1.23 (SCL), R_J1.4, R_JP4.1 (A), R_TRRS1.3
R_SDA: R_IO1.22 (SDA), R_J1.3, R_JP3.1 (A), R_TRRS1.4
R_SPI_CLK: R_S3_Pinout1.6, R_T-Display-S3.7 (12)
R_SPI_CS: R_S3_Pinout1.4, R_T-Display-S3.5 (10)
R_SPI_D: R_S3_Pinout1.5, R_T-Display-S3.6 (11)
R_SPI_Q: R_S3_Pinout1.7, R_T-Display-S3.8 (13)
R_U1_RXD: R_S3_Pinout1.3, R_T-Display-S3.17 (18)
R_U1_TXD: R_S3_Pinout1.2, R_T-Display-S3.18 (17)
R_VBAT: R_BAT_EXT1.1, R_BAT_EXT2.1, R_JP2.1 (A), R_SWB1.3 (COM)
R_VLED: R_C1.1, R_C2.1, R_C3.1, R_C4.1, R_JP2.2 (C), R_LED1.1 (VDD), R_LED2.1 (VDD), R_LED3.1 (VDD), R_LED4.1 (VDD), R_LED5.1 (VDD), R_LED6.1 (VDD), R_LED7.1 (VDD), R_LED8.1 (VDD), R_LED9.1 (VDD), R_LED10.1 (VDD), R_LED11.1 (VDD), R_LED12.1 (VDD), R_LED13.1 (VDD), R_LED14.1 (VDD), R_LED15.1 (VDD), R_LED16.1 (VDD), R_LED17.1 (VDD), R_LED18.1 (VDD), R_LED19.1 (VDD), R_LED20.1 (VDD), R_LED21.1 (VDD), R_LED22.1 (VDD), R_LED23.1 (VDD), R_LED24.1 (VDD), R_LED25.1 (VDD), R_LED26.1 (VDD), R_TP_VCC1.1

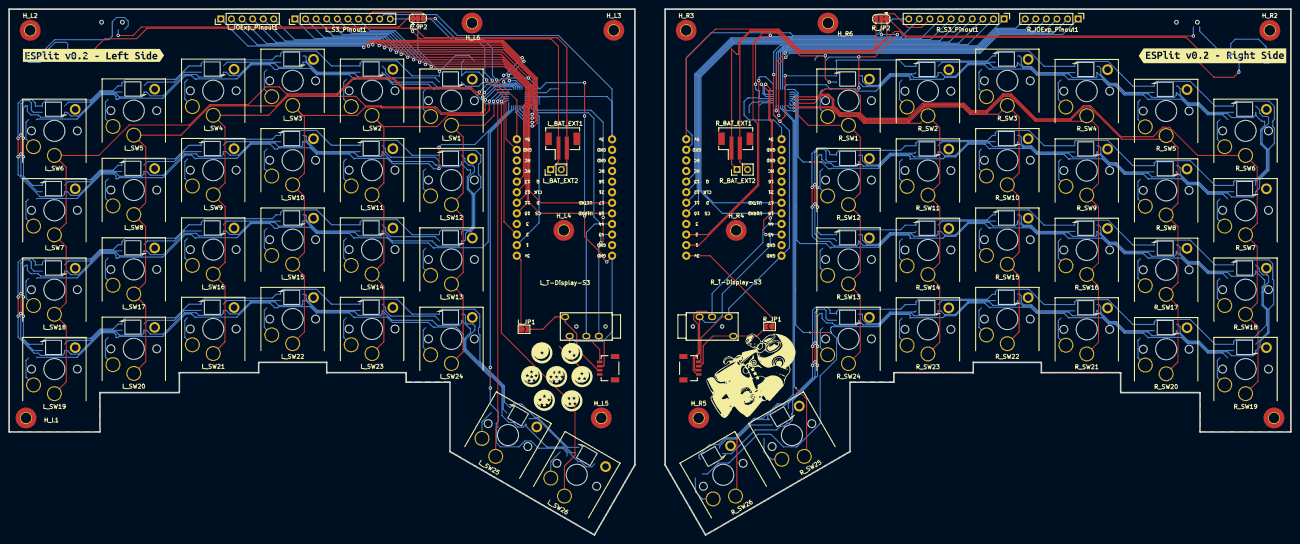
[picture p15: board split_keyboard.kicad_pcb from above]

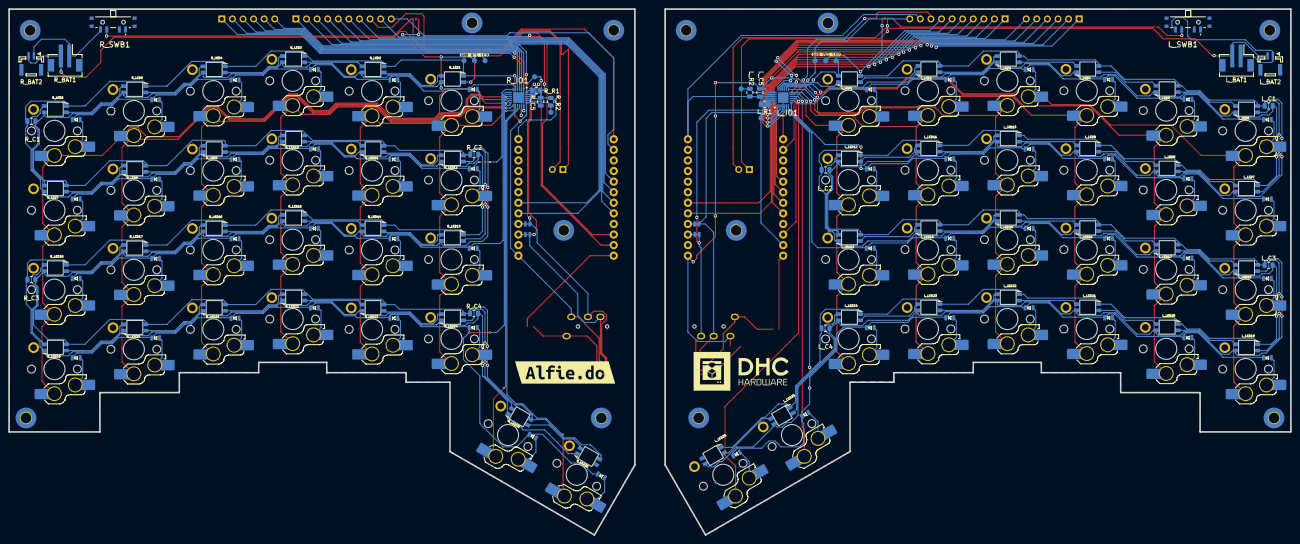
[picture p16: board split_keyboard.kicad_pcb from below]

Board: 2 copper layers, 307.5 x 126.2 mm, 227 parts (91 on the bottom side), 180 nets.

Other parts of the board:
kibuzzard-65EF74B4, kibuzzard-65EF74B4#2: G***; kibuzzard-65EF74B4
kibuzzard-6602E1CF: G***; kibuzzard-6602E1CF
kibuzzard-6603142B: G***; kibuzzard-6603142B
kibuzzard-6603143E: G***; kibuzzard-6603143E

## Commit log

2024-01-30 Init Commit
    [1_Male_Pin_2.54_mm.SLDPRT, Ecran.SLDPRT, LCD_3D.SLDASM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]
2024-02-01 adding readme
    [T-Display-S3.STEP, TCA8418RTWR.stp, base_plate.kicad_pcb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]
2024-02-01 Changed size of pcb page
2024-02-01 - Made a custom form of the key - Brang back the MINI-E lib, it was used for sch
    [SW_Hotswap_Kailh_Choc_V1.stp, split_keyboard.kicad_sch]
2024-02-05 - Changed files for next version's keyboard layout - Added instructions on how to use kb's layout file - Modified a bit the LED footprint - Modified all names for symbols and part inside the pcb and 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
    [split_keyboard.kicad_sch]
2024-02-06 - Routed most of diode-switch-caps tracks
    [split_keyboard.kicad_sch]
2024-02-11 - Located with exact coordinates the footprints moved.
    [split_keyboard.kicad_pcb]
2024-02-15 added more components and fix some in sch
    [split_keyboard.kicad_pcb, split_keyboard.kicad_sch]
2024-02-21 Right side almost done
    [split_keyboard.kicad_pcb, split_keyboard.kicad_sch]
2024-02-26 -Almost done
    [split_keyboard.kicad_pcb, split_keyboard.kicad_sch]
2024-02-27 added outline and holes
    [split_keyboard.kicad_pcb, split_keyboard.kicad_sch, test.dxf]
2024-02-27 holes located, kinda ready to send to production
    [split_keyboard.kicad_sch]
2024-03-13 Added all TPs
    [split_keyboard.kicad_sch]
2024-03-13 Finished board with plates done.
    [split_keyboard.kicad_sch]
2024-03-13 deleting some files and added gitignore
    [test.dxf]
2024-03-26 Added images and logo
    [split_keyboard.kicad_pcb]
2024-03-26 Added images to silkscreen
    [split_keyboard.kicad_pcb]
2024-04-07 commiting changes before change of name
    [base_plate-B_Cu.gbr, base_plate-B_Mask.gbr, base_plate-B_Silks.gbr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]
2024-04-08 fixed choc custom footprint ; added folders to gitignore
    [ESPlit.kicad_sch]
2024-04-13 cleaning up folders
    [base_plate-B_Cu.gbr, base_plate-B_Mask.gbr, base_plate-B_Silks.gbr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]
